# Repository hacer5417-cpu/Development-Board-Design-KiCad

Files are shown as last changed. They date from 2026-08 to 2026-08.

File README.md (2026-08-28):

# STM32 Development Board Design 

An open-source, custom STM32 microcontroller development board designed from scratch using **KiCad**. This project covers the entire hardware development lifecycle, including schematic capture, component selection, power management design, two-layer PCB layout routing, and 3D visualization.

---

## Hardware Gallery & Visuals

### 1. Schematic Design & Architecture


*Clean and structured schematic diagram featuring the STM32 microcontroller pinouts, crystal oscillators, decoupling capacitors, peripheral interfaces, and voltage regulation circuit.*

### 2. 3D Model View (Top Side)
Top View

*3D rendering of the populated top side, showcasing component alignments, RGB status LED, push buttons, micro-USB interface, and peripheral headers.*

### 3. 3D Model View (Bottom Side)


*3D rendering of the bottom side, featuring the power management component placement, ground planes, and custom silkscreen branding.*

---

## Technical Specifications & Features

* **EDA Tool:** KiCad (Schematic Capture & PCB Layout)
* **Microcontroller:** STM32 Series (LQFP-48 Package)
* **Power Management:** On-board low-dropout (LDO) voltage regulator circuit with proper filtering capacitors for stable operation.
* **Signal Integrity:** Designed with short return paths, clear ground plane separation, and optimized routing for high-frequency (HSE) and low-frequency (LSE) crystal oscillators.
* **UI & Peripherals:** Integrated Reset/User buttons, an RGB LED indicator, boot mode configuration jumpers, and easily accessible breakout headers for all GPIOs.
* **Aesthetics:** Custom silkscreen layer layout featuring personalized branding.

---

## Future Enhancements
* Automated hardware validation and basic firmware testing (Blinky, UART communication).
* Designing an external enclosure model using CAD tools.

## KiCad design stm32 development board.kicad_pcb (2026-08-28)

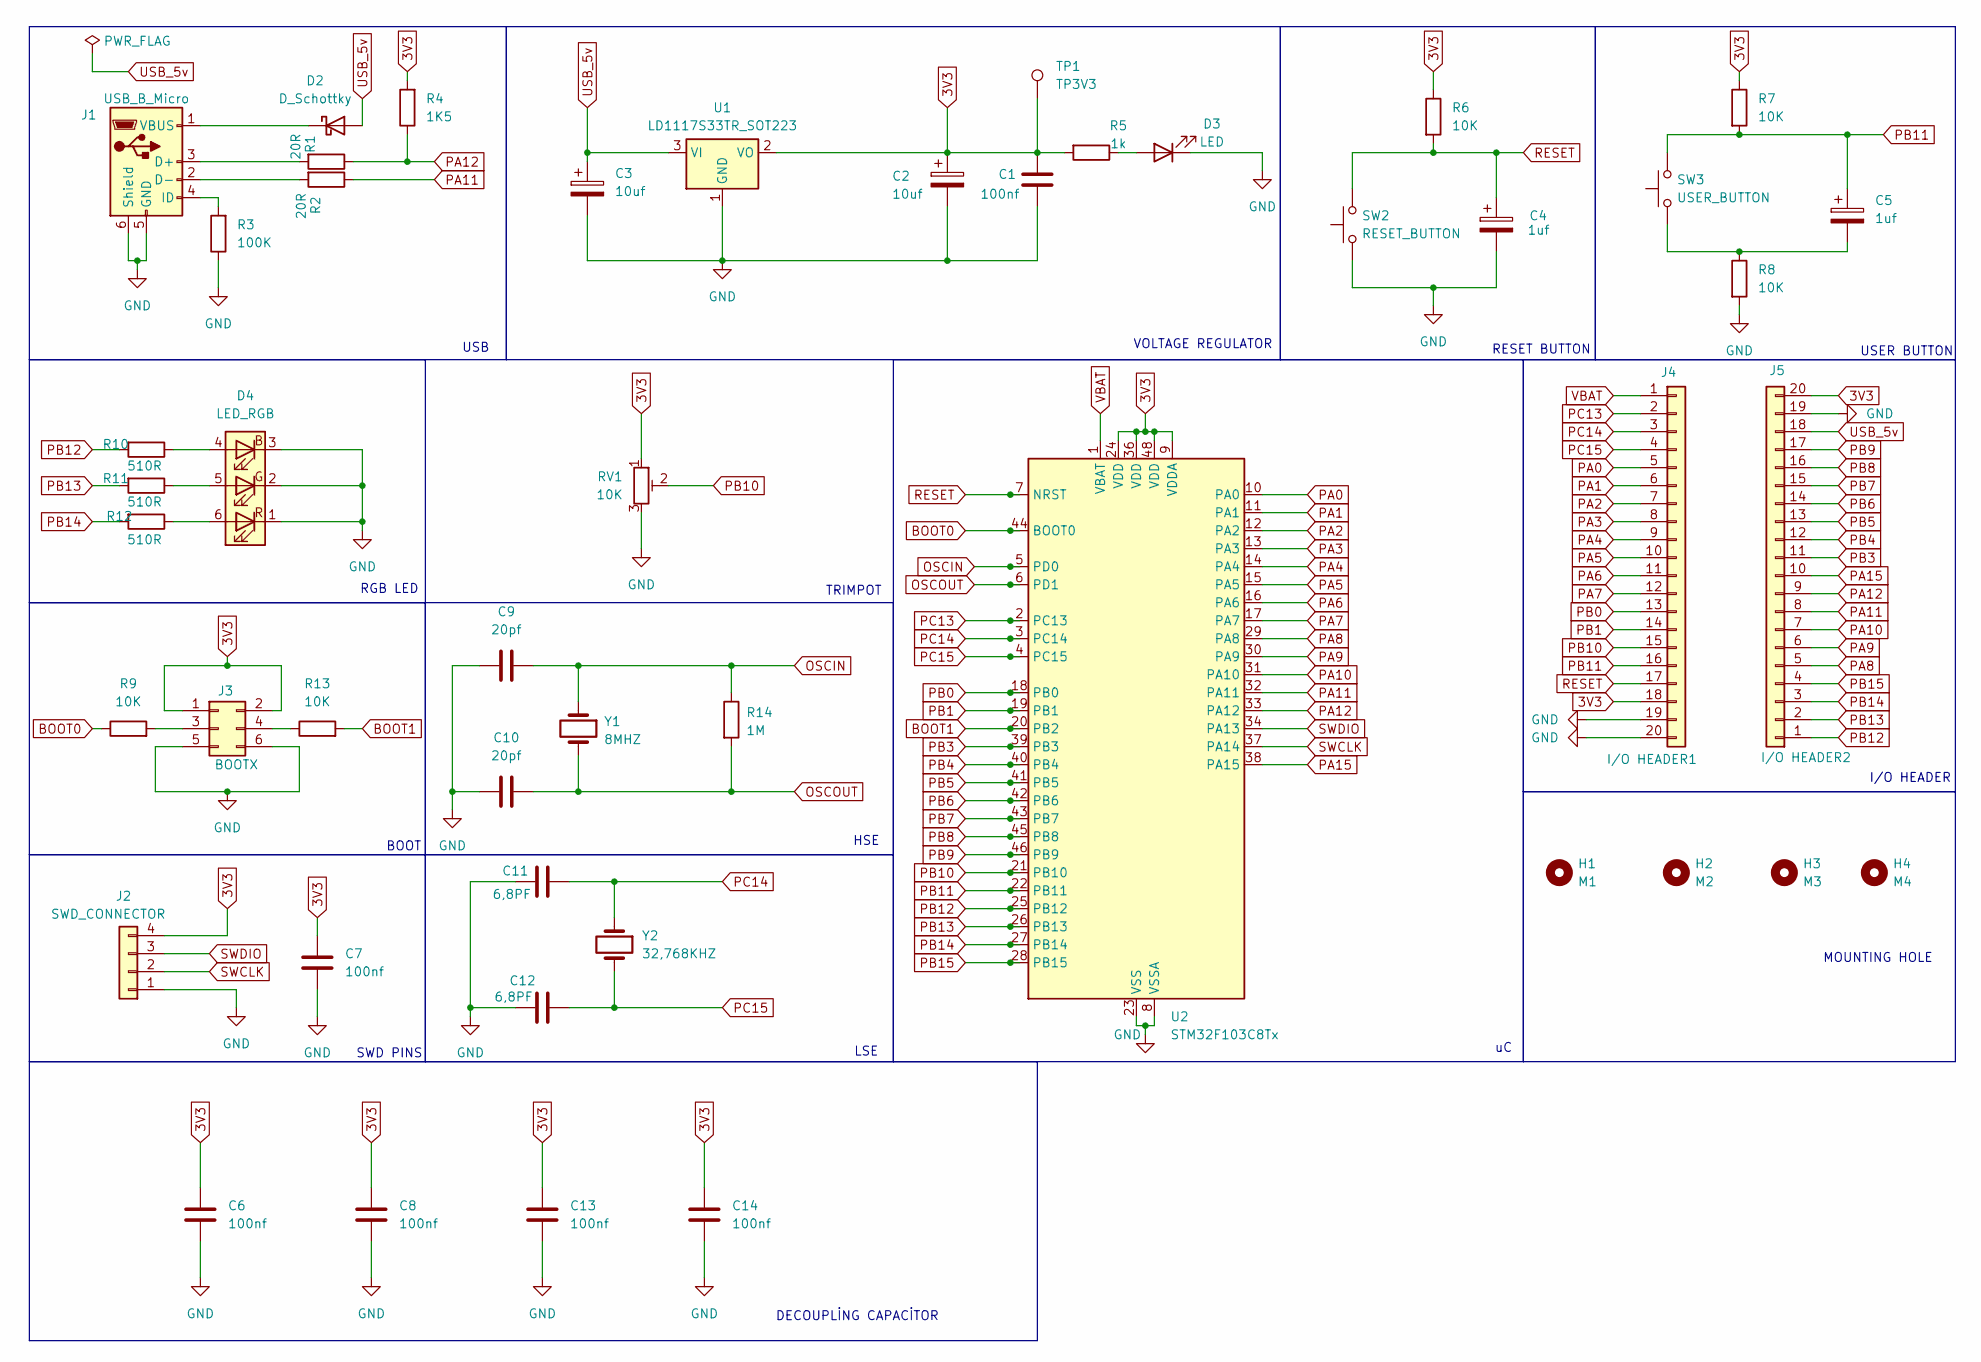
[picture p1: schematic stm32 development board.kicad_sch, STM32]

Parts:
C1, C6, C7, C8, C13, C14: 100nf; C_0603_1608Metric
C2, C3: 10uf; CP_EIA-1608-08_AVX-J
C4, C5: 1uf; CP_EIA-1608-08_AVX-J
C9, C10: 20pf; C_0603_1608Metric
C11, C12: 6,8PF; C_0603_1608Metric
D2: D_Schottky; D_TUMD2
D3: LED; LED_0805_2012Metric
D4: LED_RGB; LED_RGB_5050-6
H1: M1; MountingHole_2.2mm_M2_Pad_Via
H2: M2; MountingHole_2.2mm_M2_Pad_Via
H3: M3; MountingHole_2.2mm_M2_Pad_Via
H4: M4; MountingHole_2.2mm_M2_Pad_Via
J1: USB_B_Micro; USB_Micro-B_Molex_47346-0001
J2: SWD_CONNECTOR; PinHeader_1x04_P2.54mm_Horizontal
J3: BOOTX; PinHeader_2x03_P2.54mm_Vertical
J4: I/O HEADER1; PinHeader_1x20_P2.54mm_Vertical
J5: I/O HEADER2; PinHeader_1x20_P2.54mm_Vertical
R1, R2: 20R; R_0603_1608Metric
R3: 100K; R_0603_1608Metric
R4: 1K5; R_0603_1608Metric
R5: 1k; R_0603_1608Metric
R6, R7, R8, R9, R13: 10K; R_0603_1608Metric
R10, R11, R12: 510R; R_0603_1608Metric
R14: 1M; R_0603_1608Metric
RV1: 10K; Potentiometer_Bourns_3314G_Vertical
SW2: RESET_BUTTON; SW_SPST_B3U-1000P
SW3: USER_BUTTON; SW_PUSH_6mm_H8mm
TP1: TP3V3; TestPoint_Pad_D1.0mm
U1: LD1117S33TR_SOT223; SOT-223-3_TabPin2
U2: STM32F103C8Tx; LQFP-48_7x7mm_P0.5mm
Y1: 8MHZ; Crystal_HC49-4H_Vertical
Y2: 32,768KHZ; Crystal_C26-LF_D2.1mm_L6.5mm_Horizontal

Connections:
3V3: C1.1, C2.1, C6.1, C7.1, C8.1, C13.1, C14.1, J2.4, J3.1, J3.2, J4.18, J5.20, R4.2, R5.2, R6.1, R7.1, RV1.1, TP1.1, U1.2 (VO), U2.9 (VDDA), U2.24 (VDD), U2.36 (VDD), U2.48 (VDD)
BOOT0: R9.1, U2.44 (BOOT0)
BOOT1: R13.2, U2.20 (PB2)
GND: C1.2, C2.2, C3.2, C4.2, C6.2, C7.2, C8.2, C9.1, C10.1, C11.1, C12.1, C13.2, C14.2, D3.1 (K), D4.1 (RK), D4.2 (GK), D4.3 (BK), J1.5 (GND), J1.6 (Shield), J2.1, J3.5, J3.6, J4.19, J4.20, J5.19, R3.1, R8.2, RV1.3, SW2.1, U1.1 (GND), U2.8 (VSSA), U2.23 (VSS), U2.35 (VSS), U2.47 (VSS)
unnamed: C5.2, R8.1, SW3.1
unnamed: D2.1 (K), J1.1 (VBUS)
unnamed: D3.2 (A), R5.1
unnamed: D4.4 (BA), R10.1
unnamed: D4.5 (GA), R11.1
unnamed: D4.6 (RA), R12.1
unnamed: J1.3 (D+), R1.2
unnamed: J1.2 (D-), R2.2
unnamed: J1.4 (ID), R3.2
unnamed: J3.3, R9.2
unnamed: J3.4, R13.1
OSCIN: C9.2, R14.1, U2.5 (PD0), Y1.1
OSCOUT: C10.2, R14.2, U2.6 (PD1), Y1.2
PA0: J4.5, U2.10 (PA0)
PA1: J4.6, U2.11 (PA1)
PA2: J4.7, U2.12 (PA2)
PA3: J4.8, U2.13 (PA3)
PA4: J4.9, U2.14 (PA4)
PA5: J4.10, U2.15 (PA5)
PA6: J4.11, U2.16 (PA6)
PA7: J4.12, U2.17 (PA7)
PA8: J5.5, U2.29 (PA8)
PA9: J5.6, U2.30 (PA9)
PA10: J5.7, U2.31 (PA10)
PA11: J5.8, R2.1, U2.32 (PA11)
PA12: J5.9, R1.1, R4.1, U2.33 (PA12)
PA15: J5.10, U2.38 (PA15)
PB0: J4.13, U2.18 (PB0)
PB1: J4.14, U2.19 (PB1)
PB3: J5.11, U2.39 (PB3)
PB4: J5.12, U2.40 (PB4)
PB5: J5.13, U2.41 (PB5)
PB6: J5.14, U2.42 (PB6)
PB7: J5.15, U2.43 (PB7)
PB8: J5.16, U2.45 (PB8)
PB9: J5.17, U2.46 (PB9)
PB10: J4.15, RV1.2, U2.21 (PB10)
PB11: C5.1, J4.16, R7.2, SW3.2, U2.22 (PB11)
PB12: J5.1, R10.2, U2.25 (PB12)
PB13: J5.2, R11.2, U2.26 (PB13)
PB14: J5.3, R12.2, U2.27 (PB14)
PB15: J5.4, U2.28 (PB15)
PC13: J4.2, U2.2 (PC13)
PC14: C11.2, J4.3, U2.3 (PC14), Y2.1
PC15: C12.2, J4.4, U2.4 (PC15), Y2.2
RESET: C4.1, J4.17, R6.2, SW2.2, U2.7 (NRST)
SWCLK: J2.2, U2.37 (PA14)
SWDIO: J2.3, U2.34 (PA13)
USB_5v: C3.1, D2.2 (A), J5.18, U1.3 (VI)
VBAT: J4.1, U2.1 (VBAT)

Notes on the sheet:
RGB LED
BOOT
HSE
VOLTAGE REGULATOR
SWD PINS
RESET BUTTON
TRIMPOT
DECOUPLİNG CAPACİTOR
LSE
I/O HEADER
MOUNTING HOLE
USB
USER BUTTON

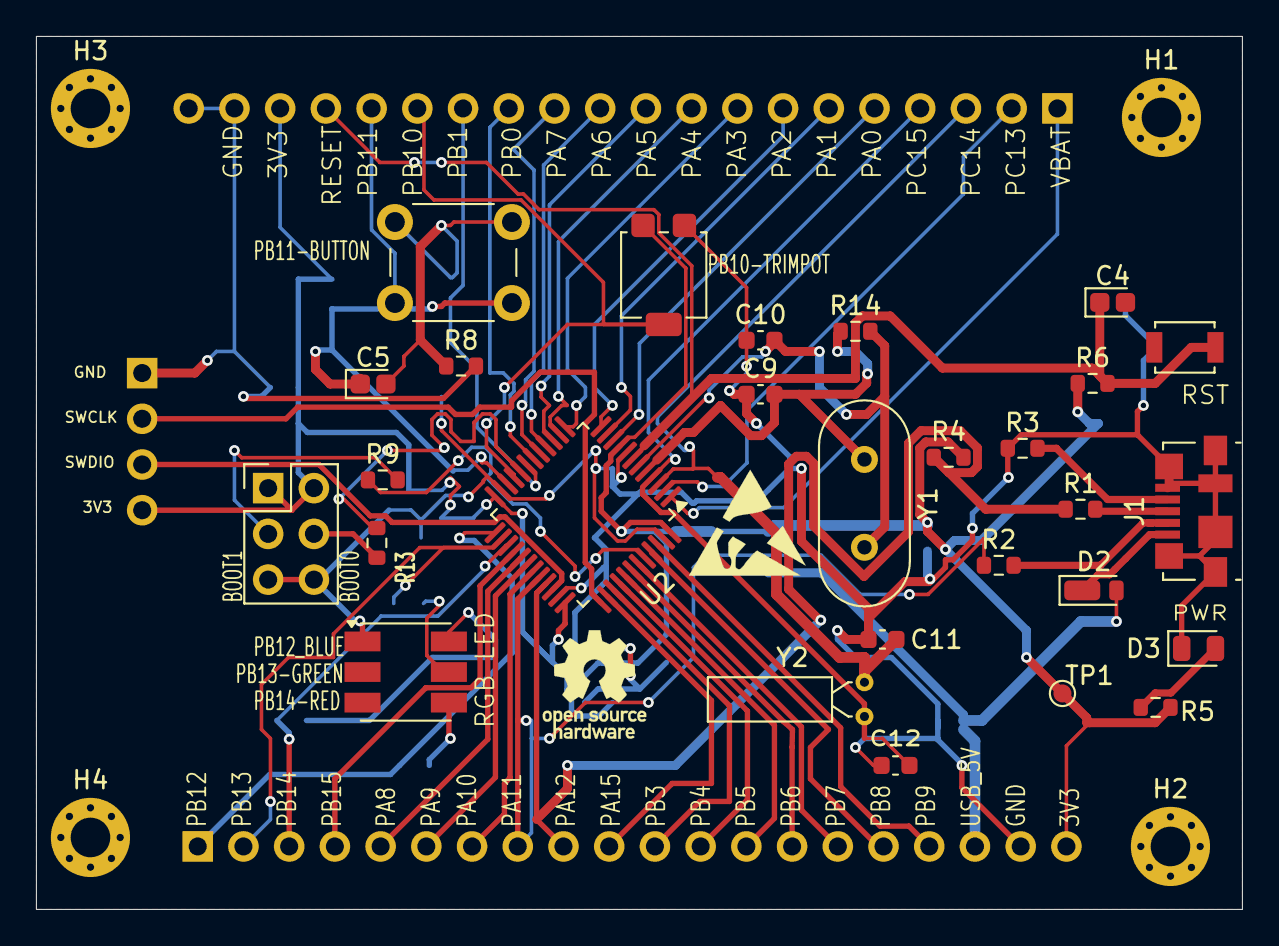
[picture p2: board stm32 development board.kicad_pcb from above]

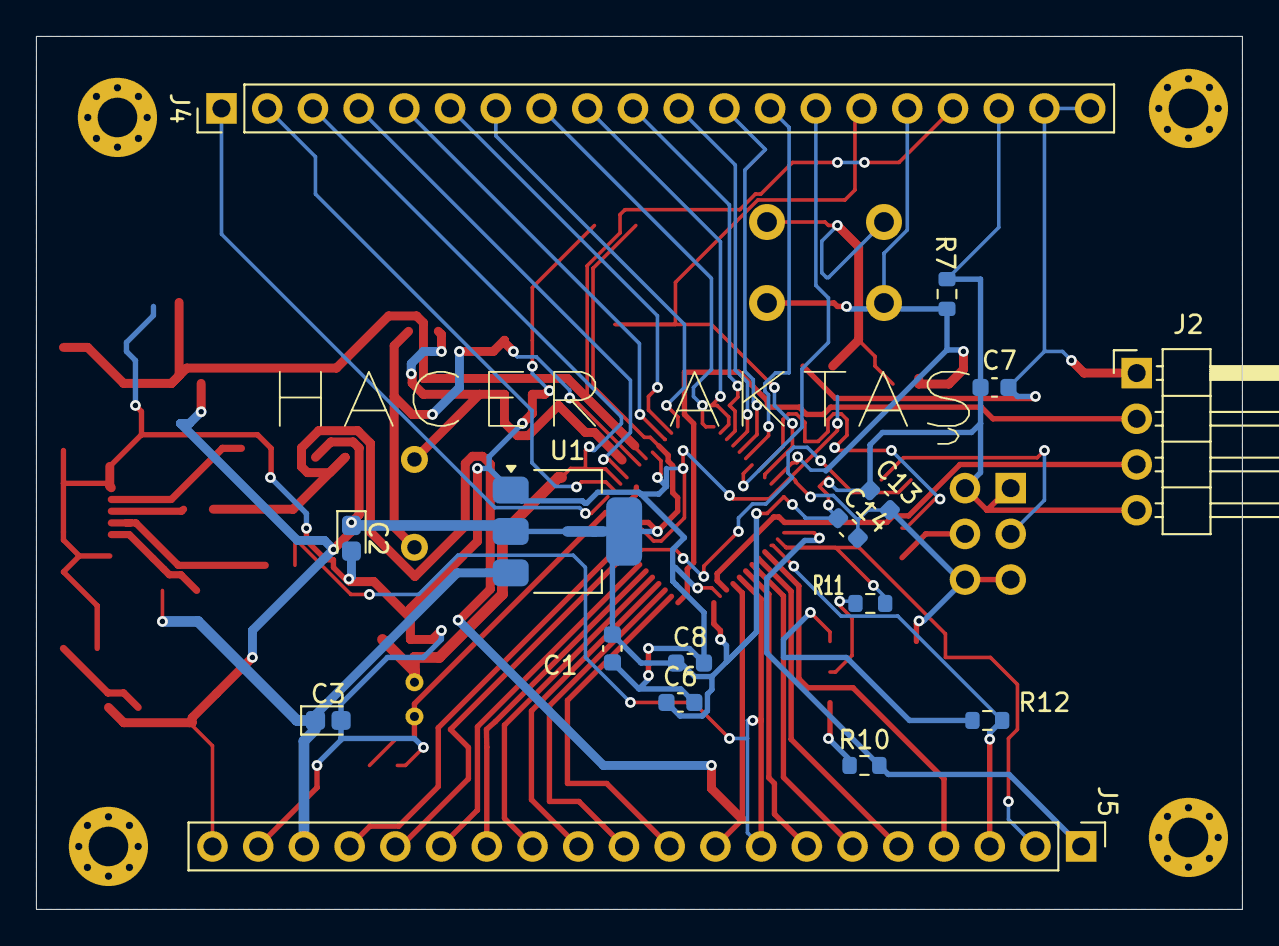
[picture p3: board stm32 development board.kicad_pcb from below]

Board: 2 copper layers, 67.0 x 48.5 mm, 48 parts (16 on the bottom side), 54 nets.
